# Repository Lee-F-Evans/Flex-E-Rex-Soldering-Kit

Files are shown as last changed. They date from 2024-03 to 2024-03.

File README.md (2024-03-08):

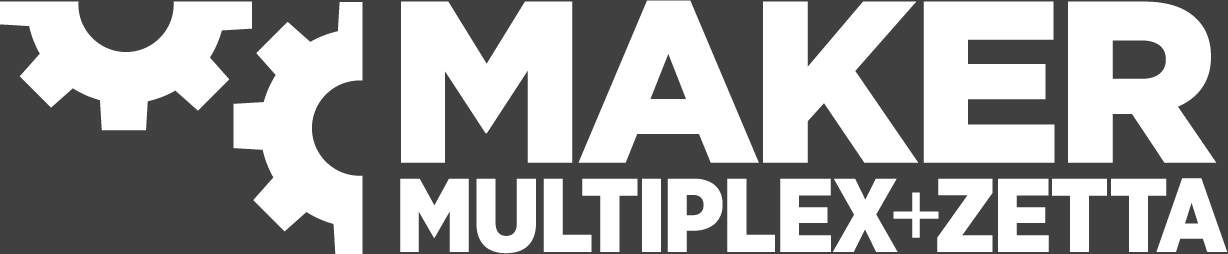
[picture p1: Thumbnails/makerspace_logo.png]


<header>
    <h1 align = "center">Flex-E-Rex-Soldering-Kit</h1>
</header>

<p align="center">
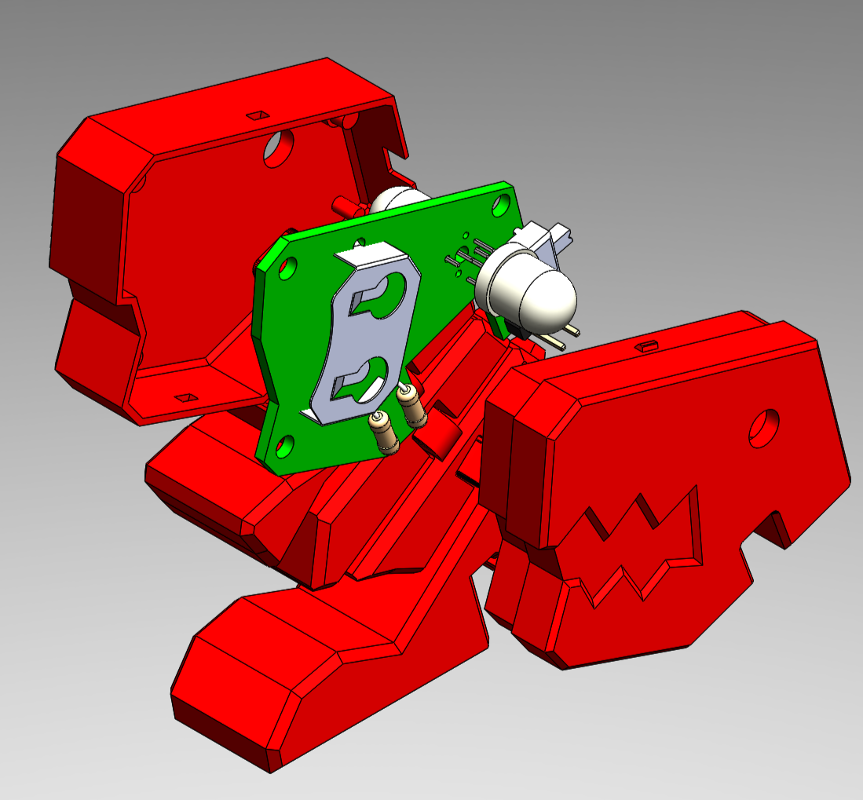
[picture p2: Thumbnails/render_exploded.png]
  
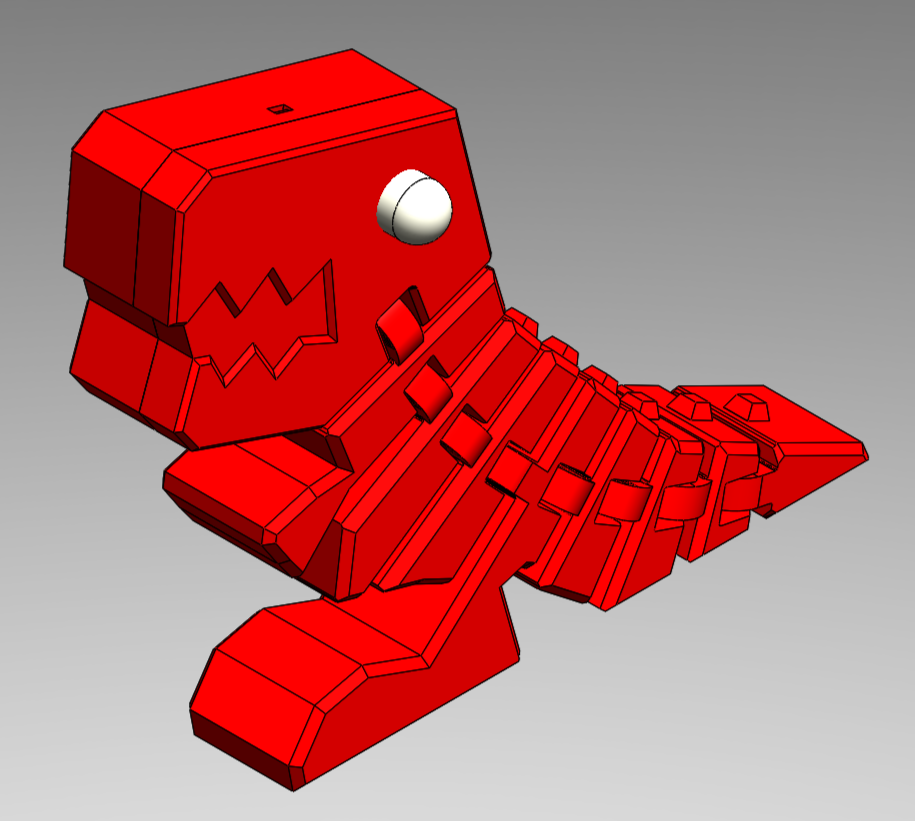
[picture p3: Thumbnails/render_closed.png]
   
</p>
<p align="center">
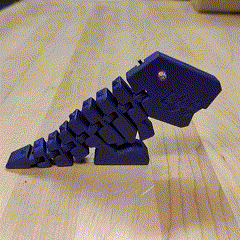
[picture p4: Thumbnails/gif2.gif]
  
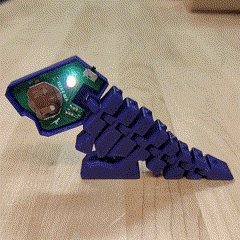
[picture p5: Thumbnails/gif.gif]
   
</p>

## About
Flex E Rex is a beginer friendly soldering project developed as educational content within the Schulich School of Engineering Makermuliplex and Zetta by Lee Evans and Connor McNeill. The contents of this repo allow for anyone to assemble these kits for themselves.

For more information about equipment, trainings and classes offered within the Makermultiplex visit https://schulich.libguides.com/m2z/. 

## How to Use
To get the kits ready for use you will need to order PCBs, 3D print the 2 enclosure parts, order the circuit components listed in the "Parts" section or found in the BOM, gather required tools and print the instructions sheet if needed.

It is recommended to briefly review the instructions before beginning assembly! The order of stems and LED spacing are important.

## Parts and Tools

### Tools:
- Soldering iron
- Lead Free Solder
- Flush cuts/Wire cutters

### Parts:
Details and links to the following components can be found in the BOM excel sheet.

| Part | Quantity |
| --- | --- |
| LED | 2 |
| Switch (PN:1825232-1) | 1 |
| Coin cell holder (PN: BK-913)|1|
|0 ohm resistor|2|
|PCB|1|
|Dino Head Top|1|
|Dino Head Bottom and Body |1|
|CR2032 coin cell battery|1|

## Fabricating PCBs
<p align="center">
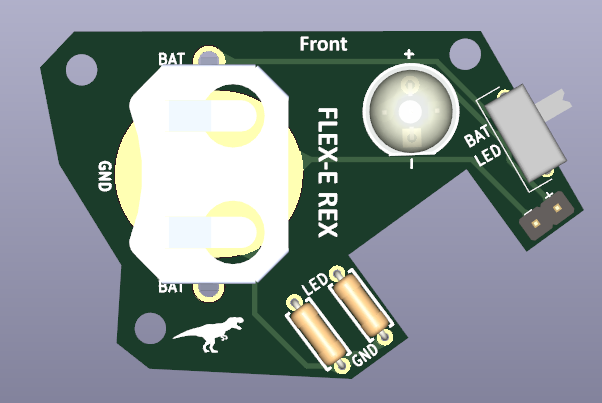
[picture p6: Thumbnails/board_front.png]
  
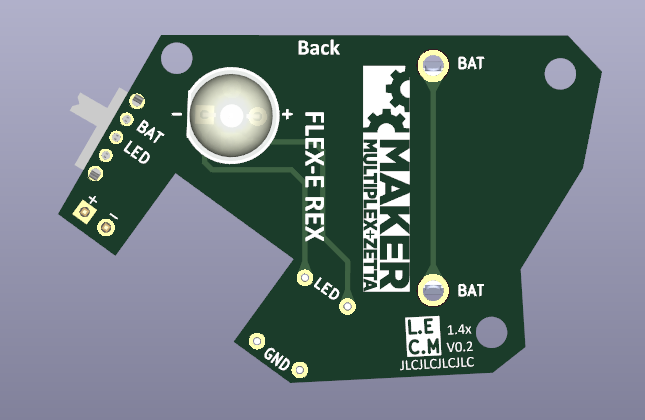
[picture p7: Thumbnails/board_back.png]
   
</p>

All files for fabrication are found in the folder `Flex-E Rex PCB Files 1_4x`. The fab files for different versions present as `Gerber and Drill Files_Rev#`. It is recomended to use the highest revision number as earlier versions may have problems.

Order more than you need! The highest expense when ordering these boards is shipping, so adding a few extra to the cart wont hurt.

### How We Ordered Our Boards 
- We used JLCPCB.com for fabrication, but any PCB fabricator should be able to produce these boards. 
- The boards are `1.6mm` thick.
- Base material is `FR4`.
- Surface finish is `lead free HASL`.
- Order number uses a `specified location`.
- All other settings were left as default.

## Printing Parts
<p align="center">
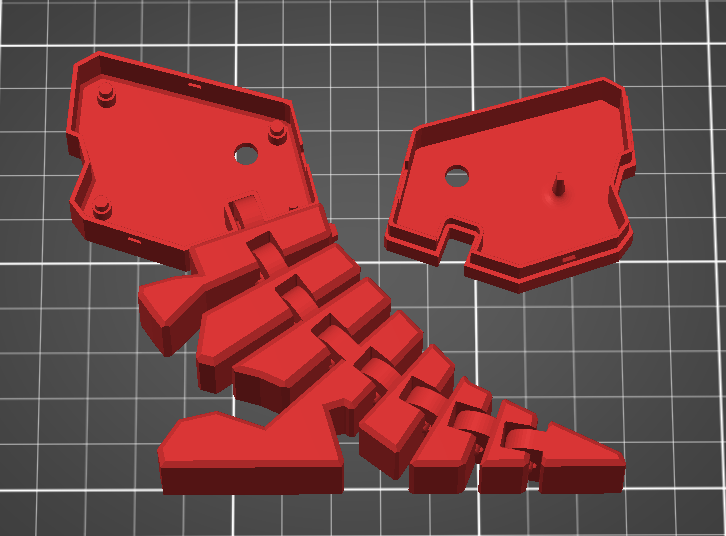
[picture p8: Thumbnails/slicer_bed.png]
  
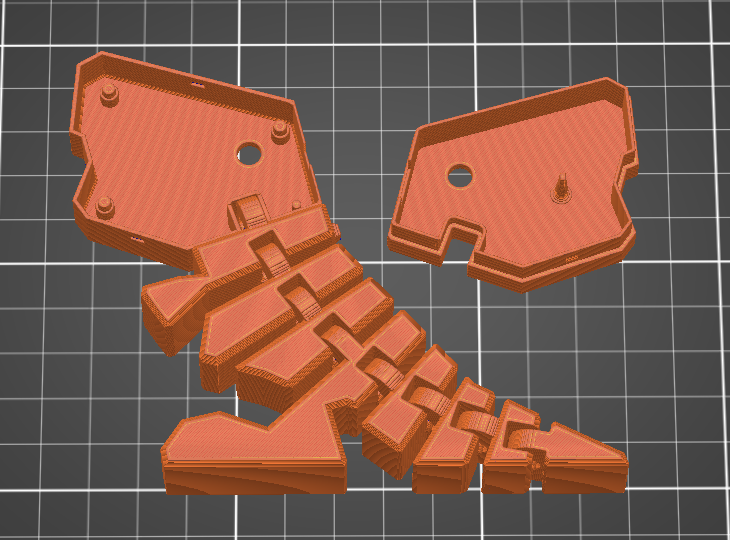
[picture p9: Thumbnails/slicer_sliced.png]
   
</p>

Most recent STL or .3mf files are found in `Flex-E Rex CAD Files 1_4x\MK2.2.X\STL`. You will need to print both `MK2.2.0 Head+Body Assy.STL` and `MK2.2.2 Head Top.STL` for a single kit. If higher versions of the model are present, use those.

We use Prusa printers and Prusa Slicer for producing our parts, but any calibrated 3D printer and slicing software will work. Below are the settings we use. 
- PLA for material
- 0.4mm diameter nozzle
- 0.2mm layer height
- 15% infill
- No supports
- No brim/raft
   
## Versioning Explained
It is always recommended to use the highest versioned PCB and enclosure files. The below information is just to explain the versioning system used. 

**#.X.X** - Indicates assembly versions. Mostly variations in size or major design changes.

**X.#.X** - Indicates PCB versions. This can be found on the back of the PCB as a "V0.X" needs to match the enclosure parts. 

**X.X.#** - Indicates eclosure part versions. 

**Note:** Any parts with matcing #.#.X versions will be compatible.

Example: *2.2.1* is assembly version 2 with PCB version 2 and enclosure parts version 1.

## Attributions
The model design for Flex-E Rex has been adapted from various remixed models originally starting from `zheng3`'s Robber Rex https://www.thingiverse.com/thing:613445. 

Thank you Kevin, Sean, and Allyne from MakerMultiplex for feedback and support on this project.

## Licencing
The enclosure parts for this project are considered a remix of the original and are licenced under [Creative Commons Share Alike Licence](https://creativecommons.org/licenses/by-sa/4.0/legalcode.en) 
<p align="left">
  
</p>

The PCB design, instructions and other content relating to the soldering kit are original designs and are licenced under [Attribution NonCommercial Share Alike (CC BY-NC-SA)](https://creativecommons.org/licenses/by-nc-sa/4.0/)
<p align="left">
  
</p>

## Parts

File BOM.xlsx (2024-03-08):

Quantity of Kits: | 1000
 | Quantity | price per unit | total price |  | link
Small bags | 1 | $36.00 |  |  | https://www.uline.ca/Product/Detail/S-2831/Reclosable-Poly-Bags/4-x-3-2-Mil-Reclosable-Bags
Large bags | 1 | $65.00 |  |  | https://www.uline.ca/Product/Detail/S-1295/Reclosable-Poly-Bags/5-x-8-2-Mil-Reclosable-Bags
coin cell holder | 1000 | $0.66 | $656.00 |  | https://www.digikey.ca/en/products/detail/mpd-memory-protection-devices/BK-913/2329371
coin cells (pack of 30) | 33.33333333 | $14.69 | $489.67 |  | https://www.amazon.ca/Lithium-Battery-Capacity-Batteries-Alkaline/dp/B08MZKNM4W
switch | 1000 | $0.50 | $497.20 |  | https://www.digikey.ca/en/products/detail/te-connectivity-alcoswitch-switches/1825232-1/4021554
resistors 0ohm | 2000 | $0.06 | $110.40 |  | https://www.digikey.ca/en/products/detail/stackpole-electronics-inc/CD18ZT0R00/1740910
LEDs (color changing) | 2000 | $0.95 | $1900.00 |  | https://www.sparkfun.com/products/11450
 |  |  | $3653.27
 | Quantity | fab cost | shipping | total
PCBs | 500 | $7.20 | $17.46 | $24.66 | https://cart.jlcpcb.com/quote/
 |  |  |  | $24.66
Grand total for # requested | $3677.93

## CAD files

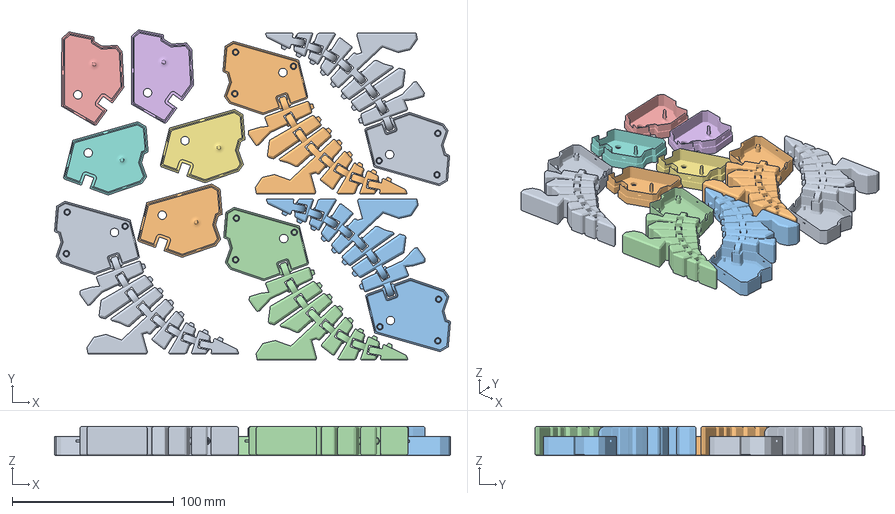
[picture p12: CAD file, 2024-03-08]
Flex-E Rex CAD Files 1_4x/MK2.2.X/Gcode/MK2.2.4 5x Final Assy_0.4n_0.2mm_PLA_MK4IS_8h36m.3mf
244.8 x 204.2 x 18.2 mm
MK2.2.4 Head+Body Assy.STL x 5
MK2.2.4 Head Top.STL x 5

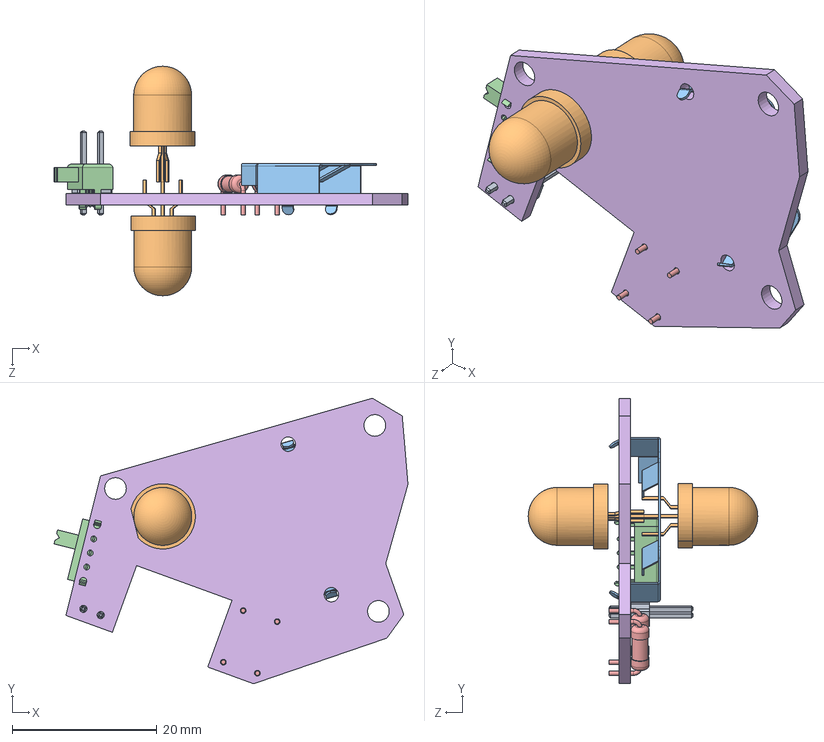
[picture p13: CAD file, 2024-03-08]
Flex-E Rex CAD Files 1_4x/MK2.2.X/Solidworks/Render Assy.SLDASM
48.8 x 39.4 x 31.7 mm
SOLID.step
SOLID-0.step x 2
SOLID-1.step
SOLID-2.step
SOLID-3.step x 2
Flex-E Rex 1_4 PCB.step

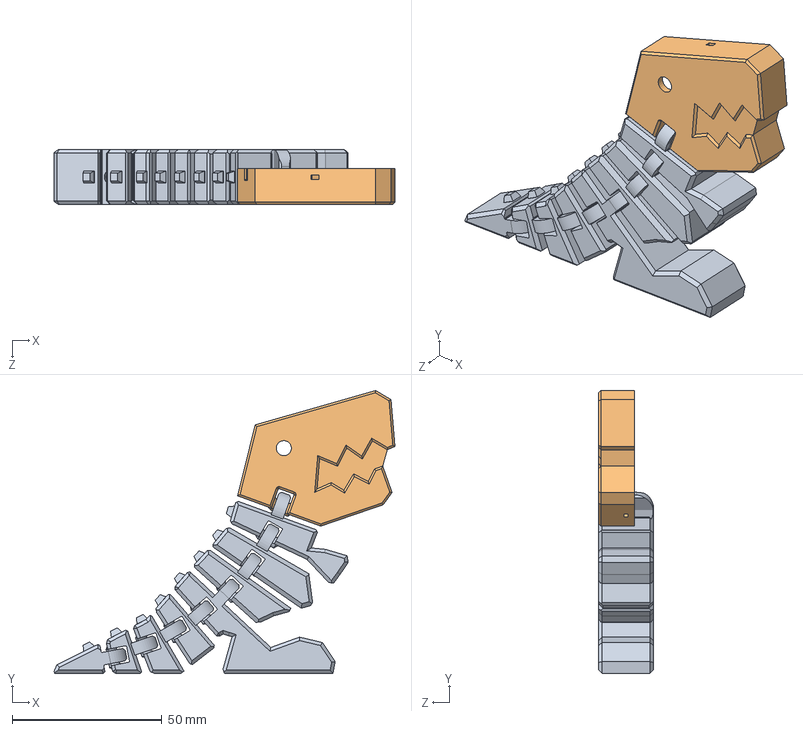
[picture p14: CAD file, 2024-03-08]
Flex-E Rex CAD Files 1_4x/MK2.1.X/Solidworks/MK2.1.0 Head+Body.SLDASM
113.8 x 94.4 x 18.2 mm
MK2.1.0 Body
MK2.1.0 Head Bottom

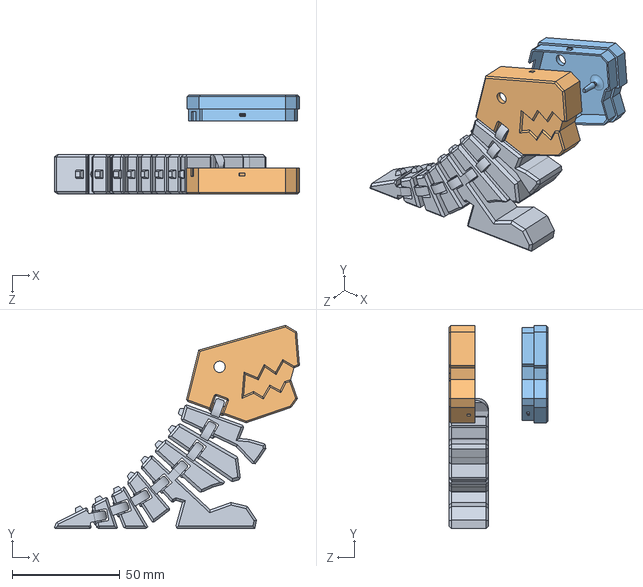
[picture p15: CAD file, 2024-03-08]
Flex-E Rex CAD Files 1_4x/MK2.2.X/Solidworks/MK2.2.4 Head+Body Assy.SLDASM
113.8 x 94.4 x 45.8 mm
MK2.2.0 Body
MK2.2.3 Head Bottom

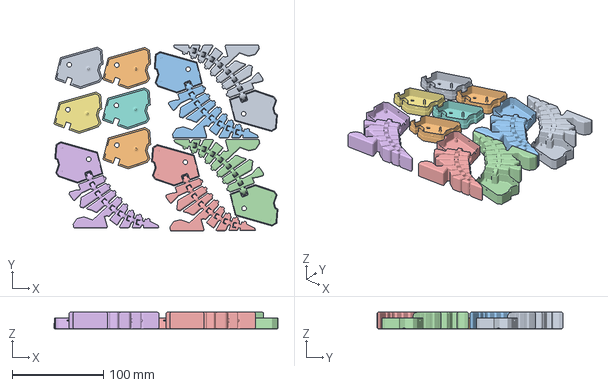
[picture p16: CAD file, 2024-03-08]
Flex-E Rex CAD Files 1_4x/MK2.1.X/Gcode/MK2.1.0 Final.3mf
245.2 x 203.3 x 18.2 mm
MK2.1.0 Head+Body.STL x 5
MK2.12 Head Top.STL x 5

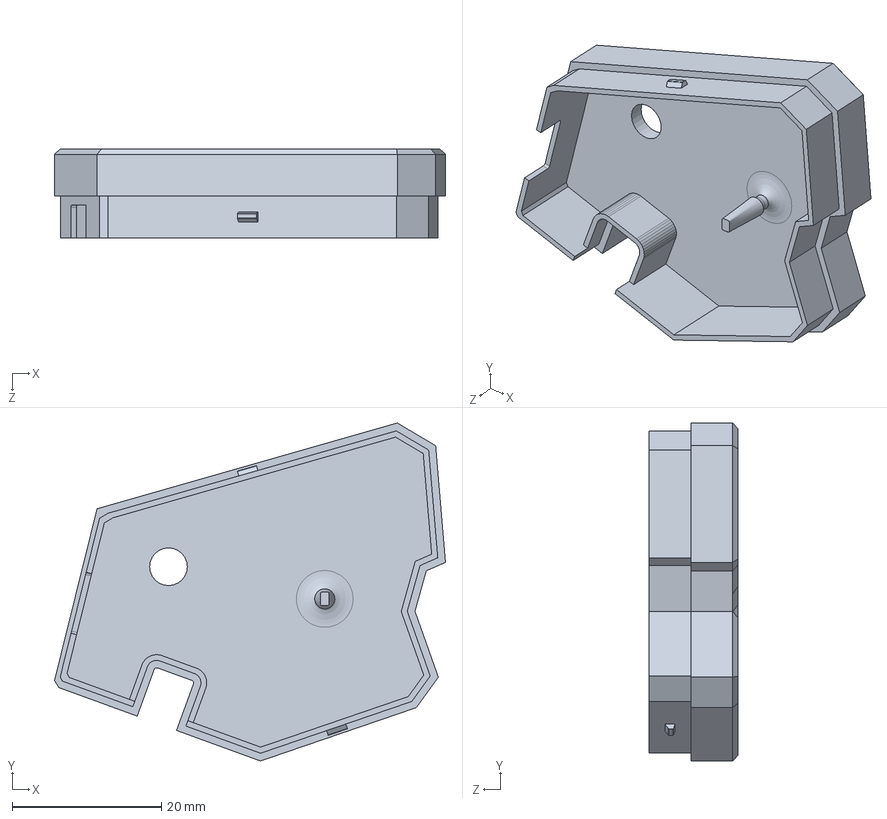
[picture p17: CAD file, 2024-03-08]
Flex-E Rex CAD Files 1_4x/MK2.1.X/Solidworks/MK2.1.2 Head Top.SLDPRT
52.4 x 45.3 x 11.9 mm

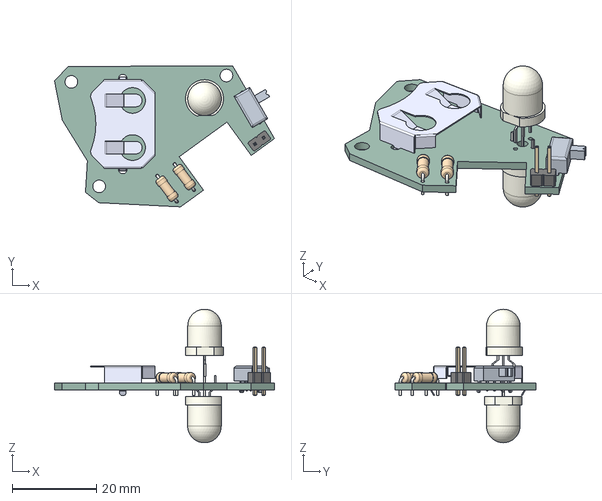
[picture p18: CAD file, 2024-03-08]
Flex-E Rex PCB Files 1_4x/kicad export PCB flexi rex 1.4.step
52.2 x 33.4 x 31.7 mm
Flex-E Rex 1_4 PCB

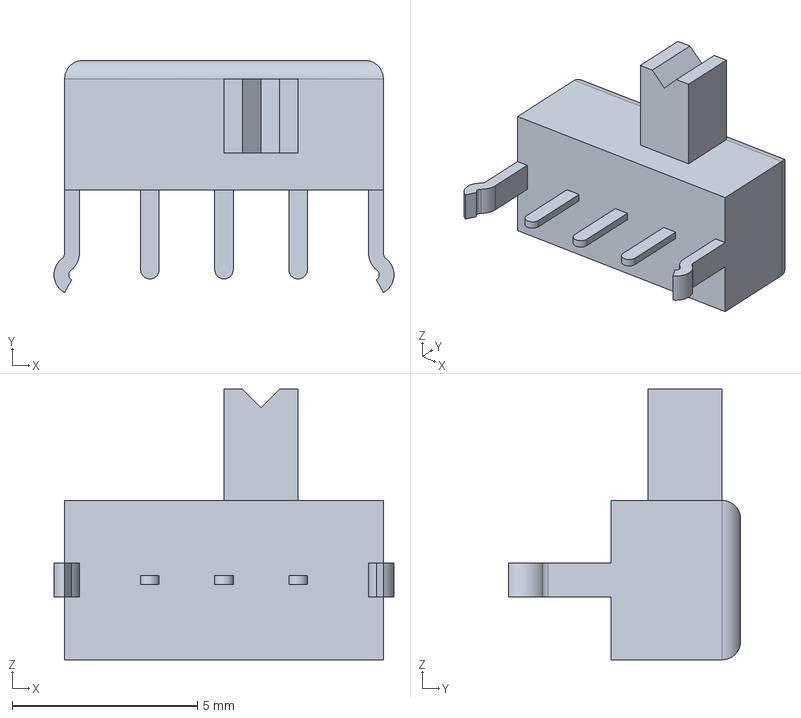
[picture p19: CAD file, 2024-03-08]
Flex-E Rex PCB Files 1_4x/Parts/1825232_1/c-1825232-1-b-3d.stp
9.17 x 6.27 x 7.30 mm

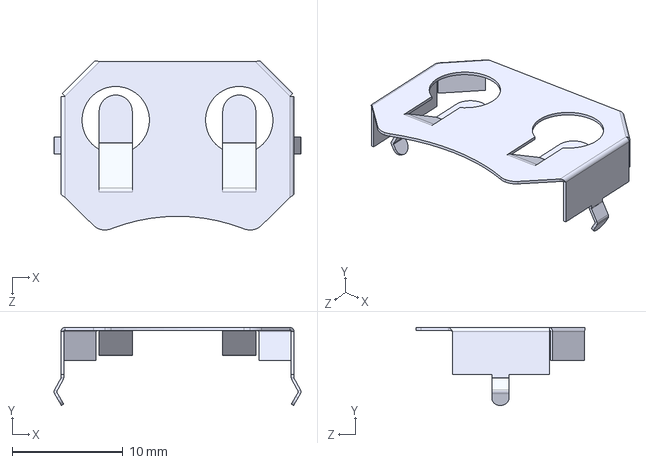
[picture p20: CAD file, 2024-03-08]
Flex-E Rex PCB Files 1_4x/Parts/BK-913/BK-913.step
22.4 x 7.06 x 15.3 mm

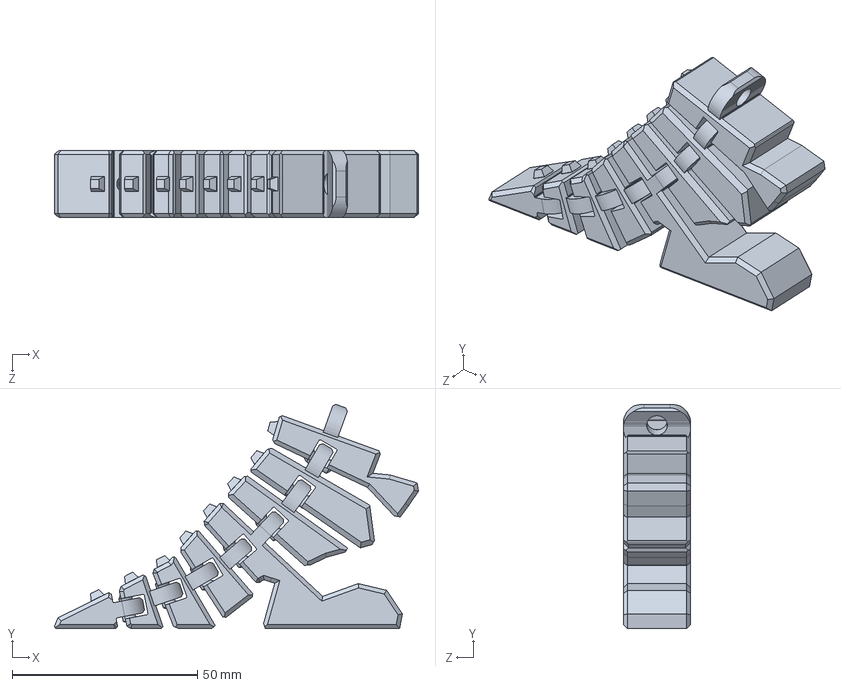
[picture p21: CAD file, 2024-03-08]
Flex-E Rex CAD Files 1_4x/MK2.1.X/Solidworks/MK2.1.0 Body.SLDPRT
98.2 x 60.5 x 18.2 mm

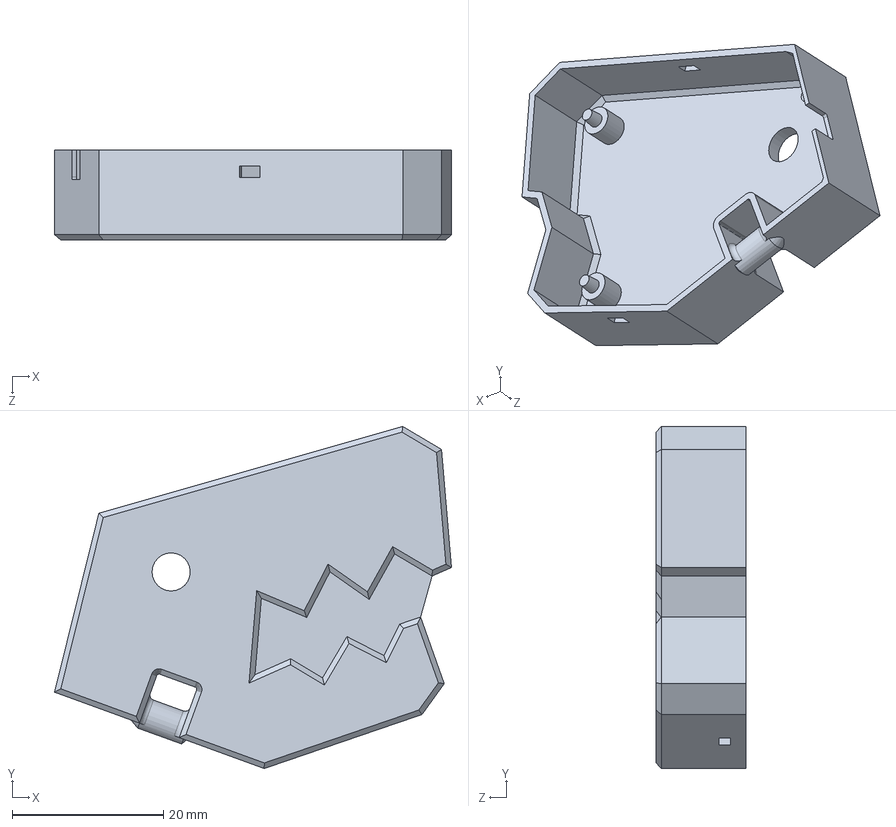
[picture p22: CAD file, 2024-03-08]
Flex-E Rex CAD Files 1_4x/MK2.1.X/Solidworks/MK2.1.0 Head Bottom.SLDPRT
52.5 x 45.3 x 11.9 mm

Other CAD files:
Flex-E Rex CAD Files 1_4x/MK2.1.X/STL/MK2.12 Head Top.STL
Flex-E Rex CAD Files 1_4x/MK2.2.X/Solidworks/MK2.2.4 Head Top.SLDPRT
Flex-E Rex CAD Files 1_4x/MK2.2.X/Solidworks/kicad export PCB flexi rex 1.4.step
Flex-E Rex CAD Files 1_4x/MK2.2.X/Solidworks/MK2.2.3 Head Bottom.SLDPRT
Flex-E Rex CAD Files 1_4x/MK2.1.X/STL/MK2.1.0 Head+Body.STL
Flex-E Rex CAD Files 1_4x/MK2.1.X/Solidworks/MK2.1.0 Head+Body.SLDPRT
Flex-E Rex CAD Files 1_4x/MK2.2.X/STL/MK2.2.4 Head Top.STL
Flex-E Rex CAD Files 1_4x/MK2.2.X/STL/MK2.2.4 Head+Body Assy.STL
Flex-E Rex CAD Files 1_4x/MK2.2.X/Solidworks/MK2.2.4 Head+Body Assy.SLDPRT

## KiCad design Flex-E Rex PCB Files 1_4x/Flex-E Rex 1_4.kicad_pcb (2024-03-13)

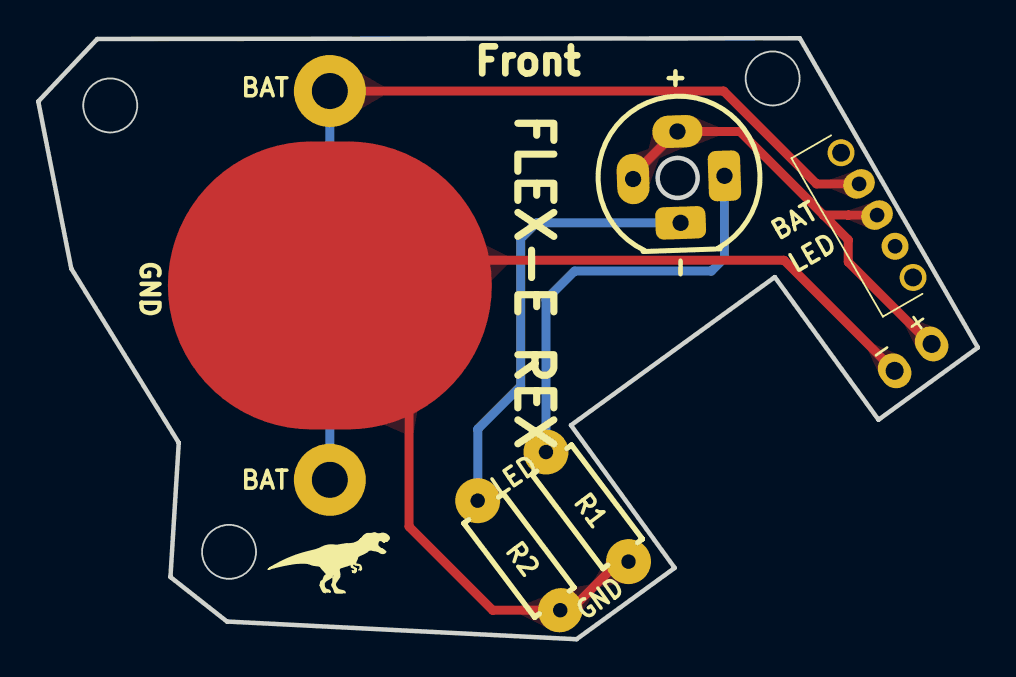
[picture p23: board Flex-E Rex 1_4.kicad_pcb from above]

Board: 2 copper layers, 52.2 x 33.4 mm, 7 parts (1 on the bottom side), 5 nets.

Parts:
BT1: BK-913; BAT_BK-913
D1, D2: LED; LED_D8.0mm-3
J1: Conn_01x02_Pin; PinHeader_1x02_P2.54mm_Vertical
R1, R2: R; R_Axial_DIN0207_L6.3mm_D2.5mm_P7.62mm_Horizontal
SW1: 1825232-1; 1825232-1_TEC

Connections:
+3V0: D1.3, D2.3, J1.1, SW1.2
GND: BT1.-, J1.2, R1.2, R2.2
unnamed: BT1.S+1, BT1.S+2, SW1.3
unnamed: D1.1 (K), R2.1
unnamed: D2.1 (K), R1.1

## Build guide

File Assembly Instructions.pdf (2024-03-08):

# Flex-E Rex Soldering Kit

Find more classes and trainings at our website! https://schulich.libguides.com/m2z

### 5. Insert the second LED from the backside while aligning the flat part on the LED with

the line on the PCB. Try to pull the LED as close to the board as possible by wiggling the LED and pushing into the board. Try to keep the LED centered and trim the wires after.

### 6. Insert coin cell and check that both LEDs work with the switch. If the LEDs do not

work, check that the battery isn’t upside down or that the LEDs aren’t soldered backwards! The flat spot on the LED should be on the same side as the flat line on the PCB.

### 7. Place the assembled PCB into the Flex-E Rex body while aligning the PCB holes with

posts and then attach the second half of the head.

# Finished!

# Flex-E Rex Soldering Kit

Find more classes and trainings at our website! https://schulich.libguides.com/m2z

### 5. Insert the second LED from the backside while aligning the flat part on the LED with

the line on the PCB. Try to pull the LED as close to the board as possible by wiggling the LED and pushing into the board. Try to keep the LED centered and trim the wires after.

### 6. Insert coin cell and check that both LEDs work with the switch. If the LEDs do not

work, check that the battery isn’t upside down or that the LEDs aren’t soldered backwards! The flat spot on the LED should be on the same side as the flat line on the PCB.

### 7. Place the assembled PCB into the Flex-E Rex body while aligning the PCB holes with

posts and then attach the second half of the head.

# Finished!

# Parts List

2x LEDs

1x Switch

1x PCB

2x Resistors
1x Battery Holder

1x Coin Cell

1x Flex-E Rex Head Half

1x Flex-E Rex Body and
Head

# Assembly Steps

1. Place the switch and battery holder as shown and solder into place from the backside. For a good solder joint apply heat to both the pad and component for 1-3 seconds and then press solder into the heated area. See the image below for tips!

### 0. Pre-heat soldering iron to ~350*C/~650*F

!!Note the orientation of the battery holder!!

### 2. Place and solder the resistors as shown. Make sure to trim the leads after soldering!

### 4. Place and solder the first LED against the spacer as shown. Align the line on the

PCB and the flat part of the LED for correct polarity. Try to center the LED and trim excess wire when done.

### 3. Locate the LED spacer in the bag or still attached to the inside of the Flex E Rex

head half and insert into the PCB eye hole as shown.

# Parts List

2x LEDs

1x Switch

1x PCB

2x Resistors
1x Battery Holder

1x Coin Cell

1x Flex-E Rex Head Half

1x Flex-E Rex Body and
Head

# Assembly Steps

1. Place the switch and battery holder as shown and solder into place from the backside. For a good solder joint apply heat to both the pad and component for 1-3 seconds and then press solder into the heated area. See the image below for tips!

### 0. Pre-heat soldering iron to ~350*C/~650*F

!!Note the orientation of the battery holder!!

### 2. Place and solder the resistors as shown. Make sure to trim the leads after soldering!

### 4. Place and solder the first LED against the spacer as shown. Align the line on the

PCB and the flat part of the LED for correct polarity. Try to center the LED and trim excess wire when done.

### 3. Locate the LED spacer in the bag or still attached to the inside of the Flex E Rex

head half and insert into the PCB eye hole as shown.

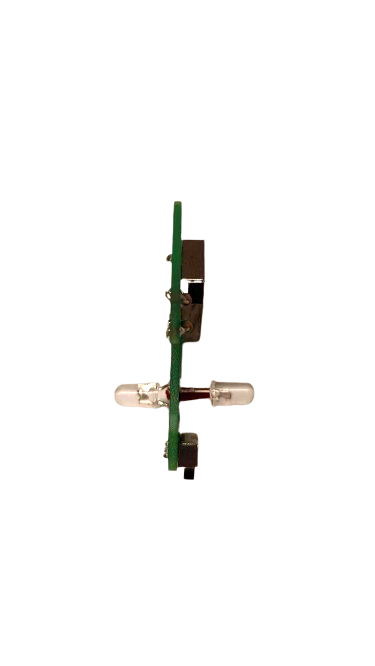
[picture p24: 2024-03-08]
Images/original_instructions/5b.png

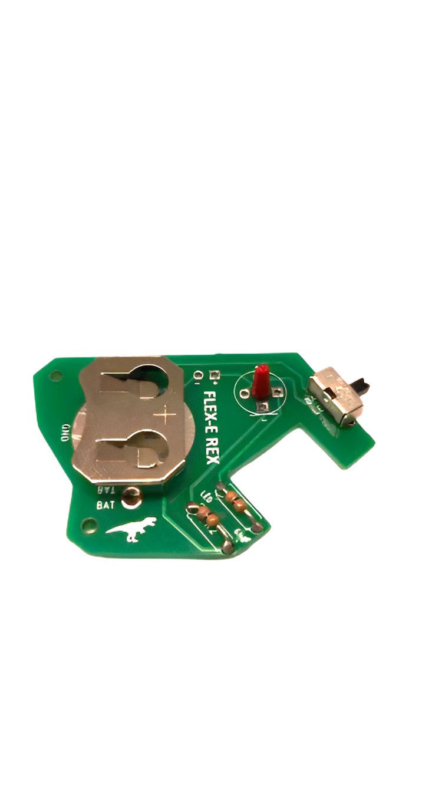
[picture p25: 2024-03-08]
Images/upscaled_instructions/3c.png

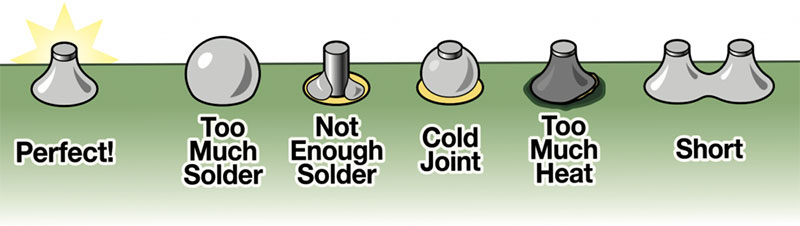
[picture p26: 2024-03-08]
Images/original_instructions/good solder joints.jpg

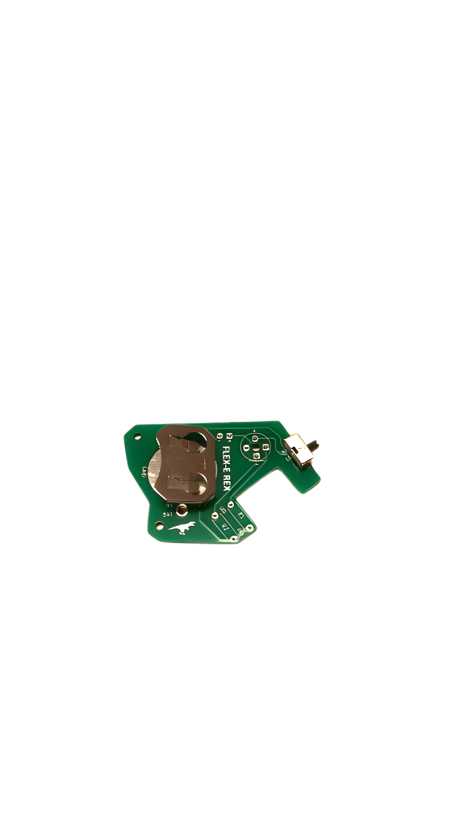
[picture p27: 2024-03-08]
Images/upscaled_instructions/1.png

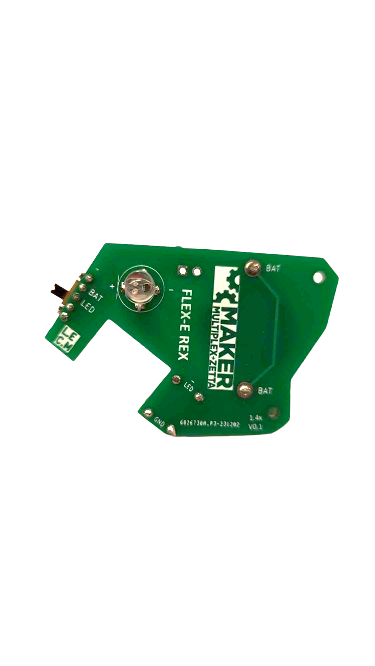
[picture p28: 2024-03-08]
Images/original_instructions/5.png

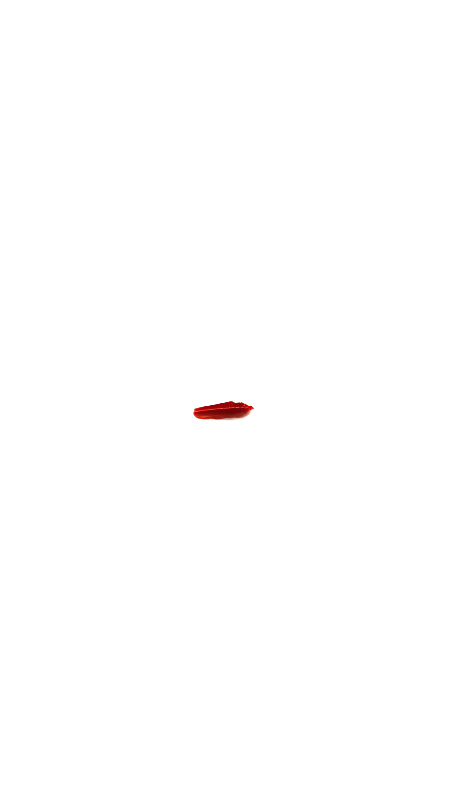
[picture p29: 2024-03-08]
Images/upscaled_instructions/3b.png

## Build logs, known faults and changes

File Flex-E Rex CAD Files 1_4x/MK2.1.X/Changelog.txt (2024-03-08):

2.1.X

-Revision format change

2.1.2

-LED support pin size increase

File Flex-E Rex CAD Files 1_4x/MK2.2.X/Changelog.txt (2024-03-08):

2.2.X

-Revision format change
-PCB locating pin addition 

2.2.2

-LED support pin size increase

MK2.2.1 Head+Body Assy

-Increased thickness to rear wall of head bottom

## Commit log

2024-03-08 Added first set of files
    Missing CAD models. Will add later after some changes by Connor.
    made small changes
    Connor Adding CAD Files
    updated led pin to be more sturdy
    Further LED Pin revisions
    updated README
    Revision formatting change + Head print fix
    Updating readme
    Changed PCB version ID to X.X.X format
    test
    Update README.md
    Test to resolve images not appearing in README
    updated to_do and testing merge
    TEST
    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
    [BK-913.step, BOM.xlsx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]
2024-03-13 added new PCB version. Increased size of pads and flipped the solder pad side for the LEDs
    [Flex-E Rex 1_4-B_Cu.gbr, Flex-E Rex 1_4-B_Mask.gbr, Flex-E Rex 1_4-B_Paste.gbr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]
